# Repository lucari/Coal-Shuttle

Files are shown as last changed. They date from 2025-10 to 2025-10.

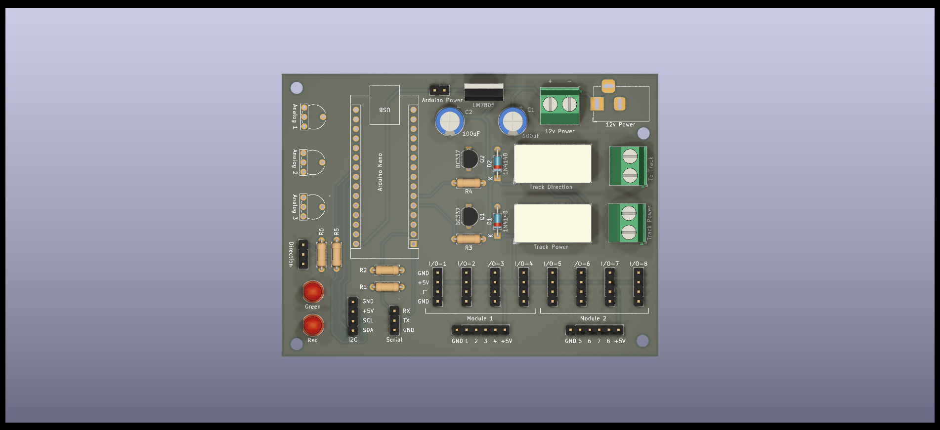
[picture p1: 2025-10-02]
Kicad/Coal-Shuttle.png

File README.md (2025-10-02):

# Coal-Shuttle

This is an Arduino based train shuttle controller for a model railway coal-hopper.

The direcrtion of the train is controlled by the on-off-on switch connected to the resistor divider on the Analog3 pin. The trimmers connected to the other Analog pins are used to control the Delay and Dwell for when the train is stopped. A Reed Switch is used to determine when a Coal Truck is in position under the shute. In forward mode, this will stop the train and turn on the converyor belt. It wil then wait for the bucket tip mercury switch to trigger, showing the coal has been delivered. After a period of time, the track power is enabled to move to the next truck.

The direction switch also controls the direction of two points that will send the train either through the Coal Loading chute path, or through the Coal Unloading path.

The pin assignment is:

  D2  - Track Power  
  D3  - Track Direction  
  D4  - Reed Switch (Train Detect)  
  D5  - Tilt Switch (Coal Tipper)  
  D6  - Conveyor Power  
  D7  - Spare  
  D8  - Points 1 Normal (Relay 1)  
  D9  - Points 1 Divert (Relay 2)  
  D10 - Points 2 Normal (Relay 3)  
  D11 - Points 2 Divert (Relay 4)  
  D12 - Red LED  
  D13 - Green LED  

  A0 - Train Detect Delay  
  A1 - Coal Tipper Dwell  
  A2 - Spare  
  A3 - Direction (0v - 2.5v - 5v)  
  
_It should be noted that there is a small design flaw on V1 of the board. The Relay module interface uses 5v from the external regulator. This should be from the Arduino 5v so it is common with the output pins. This is so it can drive the opto-coupler LED correctly (common 5v not ground). However, the external regulator 5v <ins>must</ins> be used to drive the relays (also known as JD Power). These draw too much current through the Arduino regulator. Ideally, the 5v lines should be through a jumper so the correct one can be selected for the interface type. This will be fixed on the next board. In the short term, the 5v from the I2C connector can be used for the relay 'IN' connections and the 5v on the module interface can be used for JD power._

## Arduino Code
The code is held under the Arduino folder. 

## Kicad Files
A Custom PCB was made for this and can be found under the Kicad folder.

Image of the PCB Front
Image of the PCB Rear

## Completed Boards
The image below shows a completed board. 

Image of PCB Built

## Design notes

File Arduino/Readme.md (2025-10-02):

**This is the code for the current shuttle that uses the Coal-Hopper V2 board. It will be updated for the new Coal-Shuttle board**

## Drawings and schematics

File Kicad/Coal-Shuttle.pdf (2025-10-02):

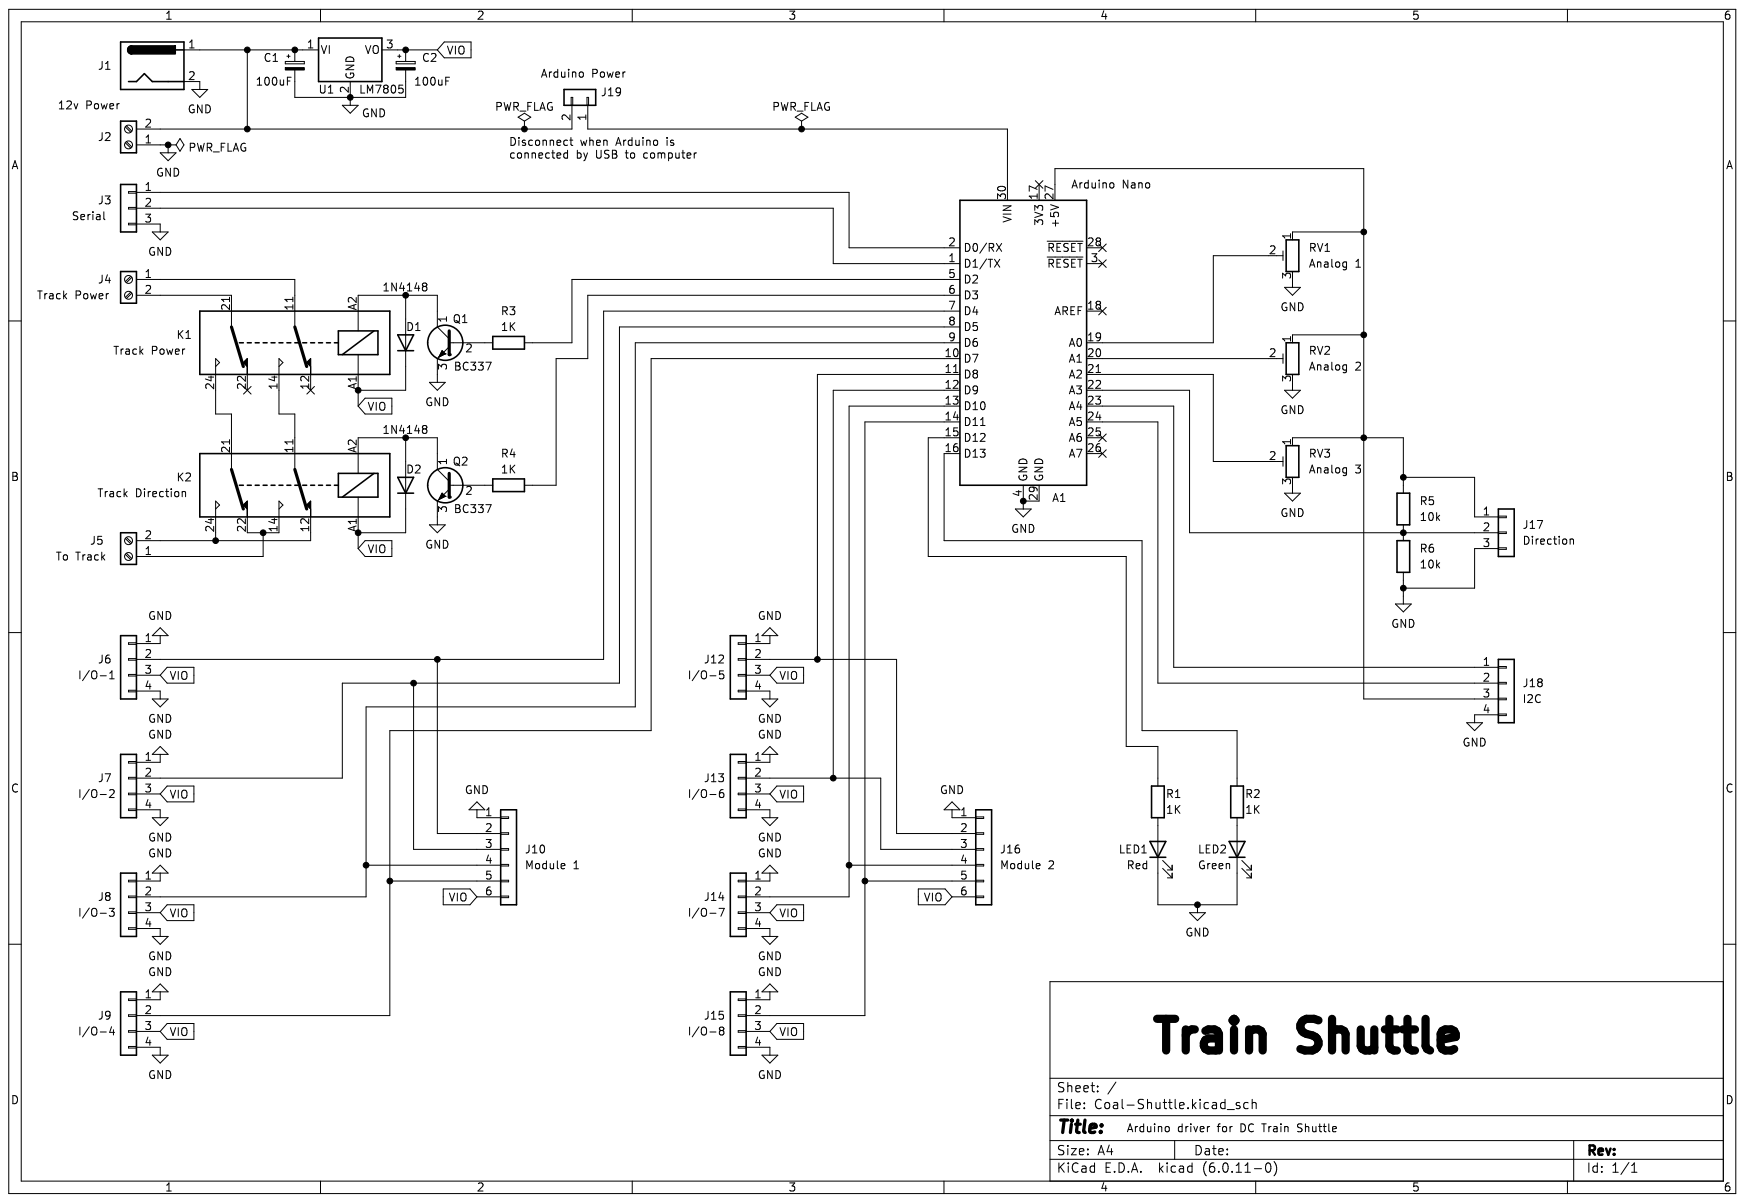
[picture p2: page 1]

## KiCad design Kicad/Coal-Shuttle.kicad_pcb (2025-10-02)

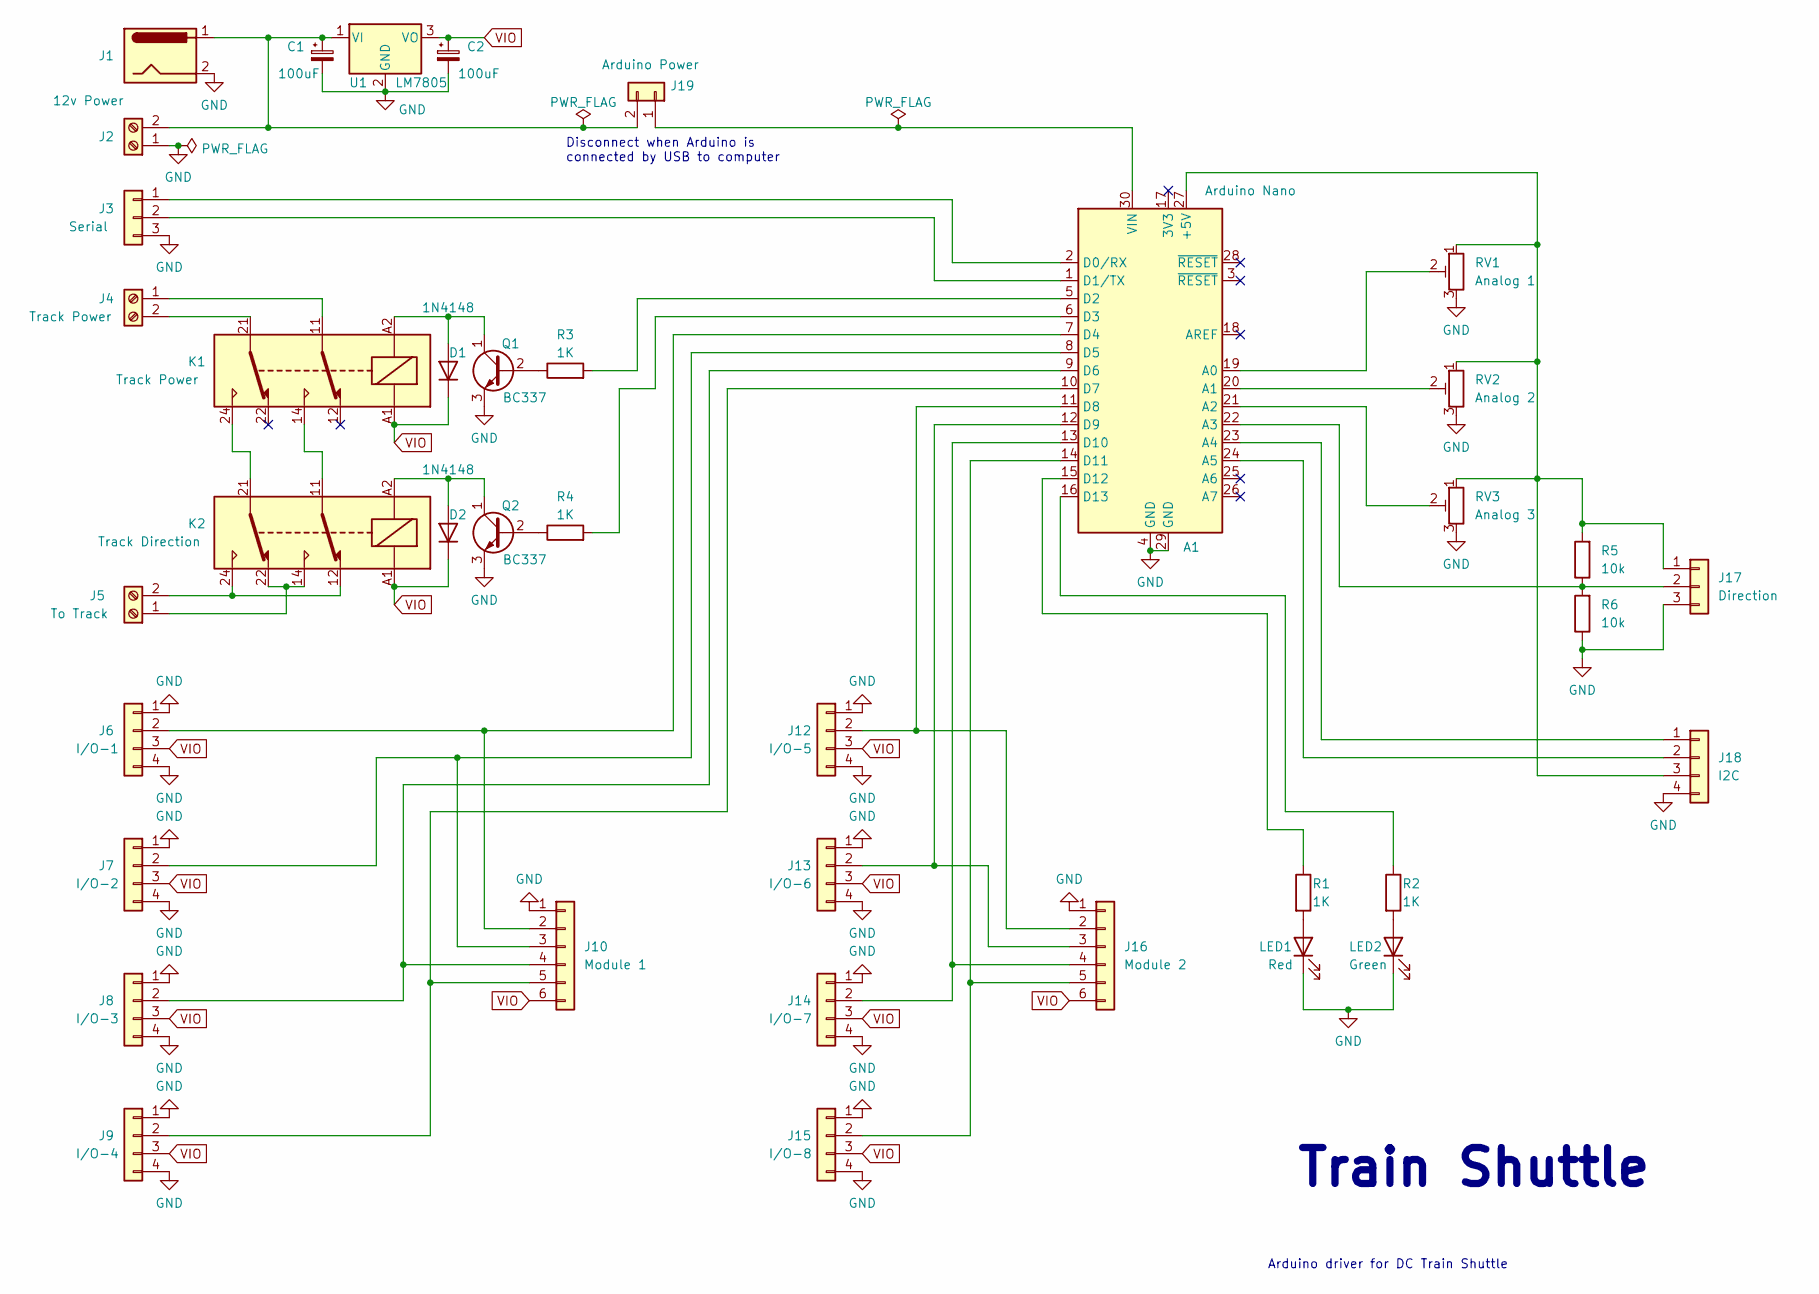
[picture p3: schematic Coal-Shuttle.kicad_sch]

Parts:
A1: Arduino Nano; Arduino_Nano
C1, C2: 100uF; CP_Radial_D7.5mm_P2.50mm
D1, D2: 1N4148; D_DO-35_SOD27_P7.62mm_Horizontal
J1: 12v Power; BarrelJack_Horizontal
J2: 12v Power; TerminalBlock_Phoenix_MKDS-1,5-2-5.08_1x02_P5.08mm_Horizont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
J3: Serial; PinHeader_1x03_P2.54mm_Vertical
J4: Track Power; TerminalBlock_Phoenix_MKDS-1,5-2-5.08_1x02_P5.08mm_Horizont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
J5: To Track; TerminalBlock_Phoenix_MKDS-1,5-2-5.08_1x02_P5.08mm_Horizont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
J6: I/O-1; PinHeader_1x04_P2.54mm_Vertical
J7: I/O-2; PinHeader_1x04_P2.54mm_Vertical
J8: I/O-3; PinHeader_1x04_P2.54mm_Vertical
J9: I/O-4; PinHeader_1x04_P2.54mm_Vertical
J10: Module 1; PinHeader_1x06_P2.54mm_Vertical
J12: I/O-5; PinHeader_1x04_P2.54mm_Vertical
J13: I/O-6; PinHeader_1x04_P2.54mm_Vertical
J14: I/O-7; PinHeader_1x04_P2.54mm_Vertical
J15: I/O-8; PinHeader_1x04_P2.54mm_Vertical
J16: Module 2; PinHeader_1x06_P2.54mm_Vertical
J17: Direction; PinHeader_1x03_P2.54mm_Vertical
J18: I2C; PinHeader_1x04_P2.54mm_Vertical
J19: Arduino Power; PinHeader_1x02_P2.54mm_Vertical
K1: Track Power; Relay_DPDT_Finder_30.22
K2: Track Direction; Relay_DPDT_Finder_30.22
LED1: Red; LED_D5.0mm
LED2: Green; LED_D5.0mm
Q1, Q2: BC337; TO-92_Inline_Wide
R1, R2, R3, R4: 1K; R_Axial_DIN0207_L6.3mm_D2.5mm_P7.62mm_Horizontal
R5, R6: 10k; R_Axial_DIN0207_L6.3mm_D2.5mm_P7.62mm_Horizontal
RV1: Analog 1; Trimpot_and_Pins
RV2: Analog 2; Trimpot_and_Pins
RV3: Analog 3; Trimpot_and_Pins
U1: LM7805; TO-220-3_Vertical

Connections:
GND: A1.4 (GND), A1.29 (GND), C1.2, C2.2, J1.2, J1.3, J2.1, J3.3, J6.1, J6.4, J7.1, J7.4, J8.1, J8.4, J9.1, J9.4, J10.1, J12.1, J12.4, J13.1, J13.4, J14.1, J14.4, J15.1, J15.4, J16.1, J17.3, J18.4, LED1.1 (K), LED2.1 (K), Q1.3 (E), Q2.3 (E), R6.1, RV1.3, RV2.3, RV3.3, U1.2 (GND); also elsewhere on the board
unnamed 1: A1.1 (D1/TX), J3.2; also elsewhere on the board
unnamed 2: A1.2 (D0/RX), J3.1; also elsewhere on the board
unnamed 3: A1.5 (D2), R3.2; also elsewhere on the board
unnamed 4: A1.6 (D3), R4.2; also elsewhere on the board
unnamed 5: A1.7 (D4), J6.2, J10.2; also elsewhere on the board
unnamed 6: A1.8 (D5), J7.2, J10.3; also elsewhere on the board
unnamed 7: A1.9 (D6), J8.2, J10.4; also elsewhere on the board
unnamed 8: A1.10 (D7), J9.2, J10.5; also elsewhere on the board
unnamed 9: A1.11 (D8), J12.2, J16.2; also elsewhere on the board
unnamed 10: A1.12 (D9), J13.2, J16.3; also elsewhere on the board
unnamed 11: A1.13 (D10), J14.2, J16.4; also elsewhere on the board
unnamed 12: A1.14 (D11), J15.2, J16.5; also elsewhere on the board
unnamed 13: A1.15 (D12), R1.1; also elsewhere on the board
unnamed 14: A1.16 (D13), R2.1; also elsewhere on the board
unnamed 15: A1.19 (A0), RV1.2; also elsewhere on the board
unnamed 16: A1.20 (A1), RV2.2; also elsewhere on the board
unnamed 17: A1.21 (A2), RV3.2; also elsewhere on the board
unnamed 18: A1.22 (A3), J17.2, R5.1, R6.2; also elsewhere on the board
unnamed 19: A1.23 (A4), J18.1; also elsewhere on the board
unnamed 20: A1.24 (A5), J18.2; also elsewhere on the board
unnamed 21: A1.27 (+5V), J17.1, J18.3, R5.2, RV1.1, RV2.1, RV3.1; also elsewhere on the board
unnamed 22: A1.30 (VIN), J19.1; also elsewhere on the board
unnamed: C1.1, J1.1, J2.2, J19.2, U1.1 (VI)
unnamed: D1.2 (A), K1.A2, Q1.1 (C)
unnamed: D2.2 (A), K2.A2, Q2.1 (C)
unnamed: J4.1, K1.11
unnamed: J4.2, K1.21
unnamed: J5.1, K2.14, K2.22
unnamed: J5.2, K2.12, K2.24
unnamed: K1.14, K2.11
unnamed: K1.24, K2.21
unnamed: LED1.2 (A), R1.2
unnamed: LED2.2 (A), R2.2
unnamed: Q1.2 (B), R3.1
unnamed: Q2.2 (B), R4.1
VIO: C2.1, D1.1 (K), D2.1 (K), J6.3, J7.3, J8.3, J9.3, J10.6, J12.3, J13.3, J14.3, J15.3, J16.6, K1.A1, K2.A1, U1.3 (VO)

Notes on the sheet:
Arduino driver for DC Train Shuttle
Disconnect when Arduino is connected by USB to computer
Train Shuttle

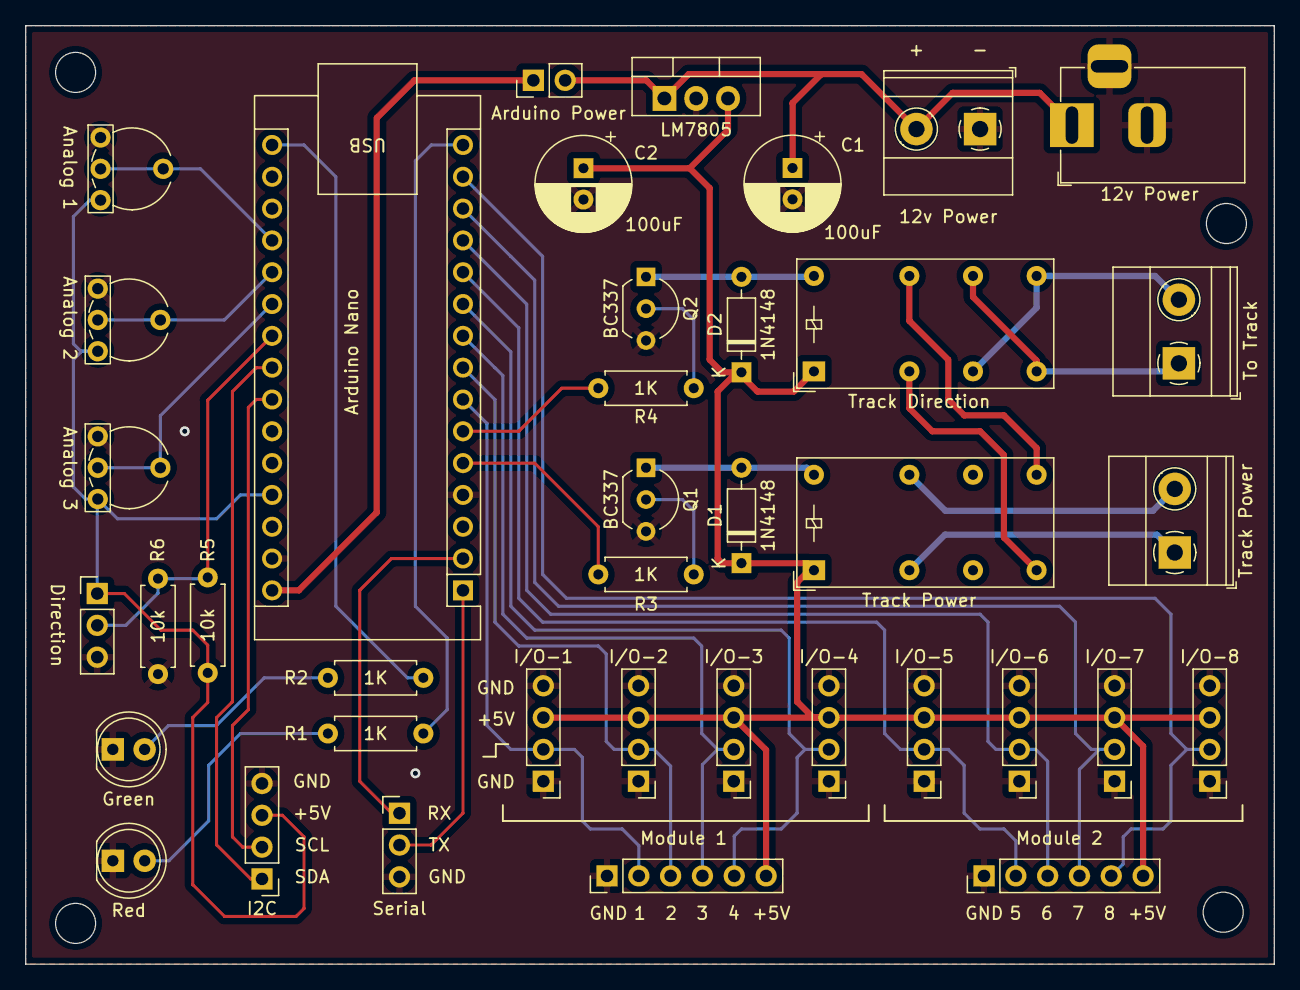
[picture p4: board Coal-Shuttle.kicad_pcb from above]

Board: 2 copper layers, 99.7 x 74.9 mm, 39 parts (0 on the bottom side), 37 nets.

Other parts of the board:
locked: Arduino Nano; Arduino_Nano

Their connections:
GND: locked.4 (GND), locked.29 (GND); also elsewhere on the board
unnamed 1: locked.1 (D1/TX); also elsewhere on the board
unnamed 2: locked.2 (D0/RX); also elsewhere on the board
unnamed 3: locked.5 (D2); also elsewhere on the board
unnamed 4: locked.6 (D3); also elsewhere on the board
unnamed 5: locked.7 (D4); also elsewhere on the board
unnamed 6: locked.8 (D5); also elsewhere on the board
unnamed 7: locked.9 (D6); also elsewhere on the board
unnamed 8: locked.10 (D7); also elsewhere on the board
unnamed 9: locked.11 (D8); also elsewhere on the board
unnamed 10: locked.12 (D9); also elsewhere on the board
unnamed 11: locked.13 (D10); also elsewhere on the board
unnamed 12: locked.14 (D11); also elsewhere on the board
unnamed 13: locked.15 (D12); also elsewhere on the board
unnamed 14: locked.16 (D13); also elsewhere on the board
unnamed 15: locked.19 (A0); also elsewhere on the board
unnamed 16: locked.20 (A1); also elsewhere on the board
unnamed 17: locked.21 (A2); also elsewhere on the board
unnamed 18: locked.22 (A3); also elsewhere on the board
unnamed 19: locked.23 (A4); also elsewhere on the board
unnamed 20: locked.24 (A5); also elsewhere on the board
unnamed 21: locked.27 (+5V); also elsewhere on the board
unnamed 22: locked.30 (VIN); also elsewhere on the board

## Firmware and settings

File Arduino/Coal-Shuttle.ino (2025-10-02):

// Define  connections

#define forwardLEDPin 2
#define reverseLEDPin 3

#define reedTestPin 4
#define tiltTestPin 5
#define forwardPin 6
#define reversePin 7

#define reedSwitchPin 8
#define tiltSwitchPin 9

#define conveyorPowerPin 10
#define trackPowerPin 11
#define trackDirectionPin 12

#define slowAnalog A0
#define fillAnalog A1

#define ANALOG_TIME 10000

#define SHUTTLE_IDLE 0
#define SHUTTLE_REVERSE 1
#define SHUTTLE_FORWARD 2
#define SHUTTLE_POSITION_TIME 3
#define SHUTTLE_FILL_WAGON 4
#define SHUTTLE_FILL_TIME 5


#define CONVEYOR_OFF 0
#define CONVEYOR_ON 1

int mode = SHUTTLE_IDLE;
int lastSwitch = SHUTTLE_IDLE;
int switchPos;

// Delay times (read from analog ports)
int slowTime = 500;
int fillTime = 1000;

bool lastLED = false;

unsigned long flashTimer;
unsigned long analogTimer = 0L;

int conveyor = CONVEYOR_OFF;

void setup() 
{
  Serial.begin(9600); // opens serial port, sets data rate to 9600 bps
  delay(100);

  Serial.println("*** Coal Train Shuttle V1 ***");   

  // Set the relay outputs high first so they don't false trigger the relays
  digitalWrite(conveyorPowerPin, HIGH);
  digitalWrite(trackPowerPin, HIGH);
  digitalWrite(trackDirectionPin, HIGH);

  // Then set them as outputs
  pinMode(conveyorPowerPin, OUTPUT);
  pinMode(trackPowerPin, OUTPUT);
  pinMode(trackDirectionPin, OUTPUT);

  // Set the LEDs
  pinMode(forwardLEDPin, OUTPUT);
  pinMode(reverseLEDPin, OUTPUT);

  // and clear the LEDs
  digitalWrite(forwardLEDPin, LOW);
  digitalWrite(reverseLEDPin, LOW);

  // finally, set the other pins as inputs with pullups
  pinMode(reedSwitchPin, INPUT_PULLUP);
  pinMode(tiltSwitchPin, INPUT_PULLUP);
  pinMode(reedTestPin, INPUT_PULLUP);
  pinMode(tiltTestPin, INPUT_PULLUP);
  pinMode(forwardPin, INPUT_PULLUP);
  pinMode(reversePin, INPUT_PULLUP);

}


void loop()
{
  // Get Switch settings
  if (digitalRead(forwardPin) == LOW)
  {
    switchPos = SHUTTLE_FORWARD;
  }
  else if (digitalRead(reversePin) == LOW)
  {
    switchPos = SHUTTLE_REVERSE;
  }
  else
  {
    switchPos = SHUTTLE_IDLE;
  }

  // Check if it has changed
  if (switchPos != lastSwitch)
  {
    // Reset the state
    mode = switchPos;
    lastSwitch = switchPos;
  }
  else
  {
    if (mode == SHUTTLE_IDLE)
    {
      // Turn off all Relays
      digitalWrite(conveyorPowerPin, HIGH);
      digitalWrite(trackPowerPin, HIGH);
      digitalWrite(trackDirectionPin, HIGH);

      // and clear the LEDs
      digitalWrite(forwardLEDPin, LOW);
      digitalWrite(reverseLEDPin, LOW);

      // Read the trimmers for the timeout values
      if ((millis() - analogTimer) > ANALOG_TIME)
      {
        analogTimer = millis();
        
        // Slow time is 0 - 1024mS
        slowTime = analogRead(slowAnalog);
        Serial.print("Slowdown time is ");
        Serial.print(slowTime);
        Serial.println("mS");

        // Fill time is 0 - 5120mS
        fillTime = analogRead(fillAnalog) * 5;
        Serial.print("Fill time is ");
        Serial.print(fillTime);
        Serial.println("mS");

      }
    }
    else if (mode == SHUTTLE_REVERSE)
    {
      // In reverse, just power the track
      digitalWrite(conveyorPowerPin, HIGH);
      digitalWrite(trackDirectionPin, LOW);
      digitalWrite(trackPowerPin, LOW);
      
      digitalWrite(forwardLEDPin, LOW);
      digitalWrite(reverseLEDPin, HIGH);
    }
    else if (mode == SHUTTLE_FORWARD)
    {
      // Forward, power the track
      digitalWrite(conveyorPowerPin, HIGH);
      digitalWrite(trackDirectionPin, HIGH);
      digitalWrite(trackPowerPin, LOW);
      
      digitalWrite(forwardLEDPin, HIGH);
      digitalWrite(reverseLEDPin, LOW);

      // Look to see if the reed switch is triggered
      if (digitalRead(reedSwitchPin) == LOW || digitalRead(reedTestPin) == LOW)
      {
        // Yes, start the delay and move to the fill state. Turn off the LED ready
        mode = SHUTTLE_FILL_WAGON;
        digitalWrite(forwardLEDPin, LOW);
        Serial.println("Moving to Fill state");
        delay(slowTime);
        flashTimer = millis();
        lastLED = false;
      }
    }
    else if (mode == SHUTTLE_FILL_WAGON)
    {
      // When filling, power off the track and turn on the conveyor. Flash the LED. Wait for tilt.
      digitalWrite(conveyorPowerPin, LOW);
      digitalWrite(trackDirectionPin, HIGH);
      digitalWrite(trackPowerPin, HIGH);
      
      digitalWrite(reverseLEDPin, LOW);

      // Flash the LED every 0.5s
      if ((millis() - flashTimer) > 500L)
      {
        if (lastLED == true)
        {
          digitalWrite(forwardLEDPin, LOW);
          lastLED = false;
          flashTimer = millis();
        }
        else
        {
          digitalWrite(forwardLEDPin, HIGH);
          lastLED = true;
          flashTimer = millis();
        }
      }

      // Look to see if the tilt switch is triggered
      if (digitalRead(tiltSwitchPin) == LOW || digitalRead(tiltTestPin) == LOW)
      {
        // Yes, stop the conveyor immediatly
        digitalWrite(conveyorPowerPin, HIGH);

        // Turn the LED back on. Start the delay and move back to forward. 
        mode = SHUTTLE_FORWARD;
        digitalWrite(forwardLEDPin, HIGH);
        Serial.println("Tipped into wagon");
        delay(fillTime);
      }
    }
    else
    {
      // Invalid state so go idle
      mode = SHUTTLE_IDLE;
    }
  }
}
